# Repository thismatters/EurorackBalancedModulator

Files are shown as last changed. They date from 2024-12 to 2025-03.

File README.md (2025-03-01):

# Balanced Modulator

The Balanced Modulator combines to audio signals to create interesting overtones, not unlike a ring modulator but lacking many sidebands.

The circuit here is based on the [Yusynth Double Balanced Modulator](https://yusynth.net/Modular/EN/RINGMOD/index.html) with minor tweaks to make it more Eurorack friendly. The changes I've made are thus:
* Selected resistors appropriate for +/-12V rails,
* Added polarity protection so that a backward power header doesn't fry anything (twin series schotty diodes: BAT54SL),
* Full surface mount design,
* Reduced module to a single balanced modulator.

The Yusynth page is a treasure trove of information about this circuit that I am too amateur to claim as my own; please read that outstanding page before using this circuit. The page provides many details and other implementations of this circuit that you may find suitable.

The KiCAD project here uses the library/footprints [found in my companion repo](https://github.com/thismatters/EurorackKiCAD).

## Width

12hp on an Intellijel 1U rack.

## Inputs

Jacks:
- Carrier Signal: `A sin(f_1 t)`
- Modulating Signal: `B sin(f_2 t)`

## Outputs

Output jack for modulated signal: `A sin((f_1 + f_2) t) + A sin((f_1 - f_2) t)`

## Adjustment

* Set up the module to be in "AC" mode (see below).
* Set a VCO to output 1000Hz sine wave and connect it to the "carrier" input.
* Connect an oscilloscope to the output of the module.
* Adjust RV2 until the module output is flat.
* Move the VCO output to the "modulating" input.
* Adjust RV1 until the module output is flat.

### Choose Operating Mode

There are three sets of jumpers for setting whether the inputs and outputs will be AC or DC coupled.
Use three jumpers to choose how the signals will be coupled.

## Vendors

There are part numbers in the [BOM](balanced-modulator.csv) for many of the parts (not for basic passives though) at the following vendors:

* [Mouser](https://www.mouser.com): Needs no introduction. Get your ICs from here (or [digikey](https://www.digikey.com)).
* [Tayda Electronics](https://www.taydaelectronics.com/): Good supplier for passive components; audio jacks, and potentiometers. Their audio jacks are slightly smaller than the thonkiconn from thonk.
* [Love My Switches](https://lovemyswitches.com/): Has [really good knobs](https://lovemyswitches.com/anodized-aluminum-knob-the-lo-fi-1-4-smooth-shaft-12-5mm-od/) to go on those potentiometers!
* [OSHPark](https://oshpark.com/): Fast and (relatively) cheap PCB manufacturer. [V0 PCB works great!](https://oshpark.com/shared_projects/MmM817Fr)

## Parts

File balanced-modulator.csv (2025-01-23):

# | Reference | Qty | Value | Footprint | DNP | Vendor | PartNum
1 | C1, C2 | 2 | 22u 50V | Capacitor_THT:CP_Radial_D5.0mm_P2.50mm
2 | C3 | 1 | 100n | Capacitor_SMD:C_0805_2012Metric
3 | C4 | 1 | 100u 16V | Capacitor_THT:CP_Radial_D5.0mm_P2.50mm
4 | C5, C6, C7 | 3 | 1u box | Eurorack:C_Rect_Horizontal_L7.2mm_W11
5 | D1, D2 | 2 | BAT54S | Package_TO_SOT_SMD:SOT-23 |  | Mouser | 863-BAT54SLT1G
6 | J1 | 1 | Conn_02x05_Odd_Even | Eurorack:PinHeader_2x05_P2.54mm_Vertical |  | Tayda | A-2939
7 | J2, J5 | 2 | Conn_01x03_Socket | Connector_PinSocket_2.54mm:PinSocket_1x03_P2.54mm_Vertical
8 | J3, J4 | 2 | Conn_01x03_Pin | Connector_PinHeader_2.54mm:PinHeader_1x03_P2.54mm_Vertical
9 | J8 | 1 | carrier | Eurorack:AudioJack2_Tayda_A-2566 |  | Tayda | A-2566
10 | J9 | 1 | modulating | Eurorack:AudioJack2_Tayda_A-2566 |  | Tayda | A-2566
11 | J10 | 1 | out | Eurorack:AudioJack2_Tayda_A-2566 |  | Tayda | A-2566
12 | JP1, JP2, JP3 | 3 | Jumper_3_Bridged12 | Connector_PinHeader_2.54mm:PinHeader_1x03_P2.54mm_Horizontal
13 | M1, M3, M4, M6 | 4 | Screw | Eurorack:Screw_M2.5x0.45-6mm |  | Digikey | 36-29301-ND
14 | M2, M5 | 2 | Standoff | Eurorack:Standoff_M2.5x0.45-11mm |  | Digikey | 732-10549-ND
15 | R1, R2 | 2 | 10 | Resistor_SMD:R_0805_2012Metric
16 | R3, R10 | 2 | 180K | Resistor_SMD:R_0805_2012Metric
17 | R4, R7 | 2 | 12K | Resistor_SMD:R_0805_2012Metric
18 | R5, R6, R11, R14 | 4 | 2.7K | Resistor_SMD:R_0805_2012Metric
19 | R8, R9 | 2 | 1.5K | Resistor_SMD:R_0805_2012Metric
20 | R12, R13, R15 | 3 | 6.8K | Resistor_SMD:R_0805_2012Metric
21 | R16, R17, R20, R21 | 4 | 15K | Resistor_SMD:R_0805_2012Metric
22 | R18, R19 | 2 | 1.2K | Resistor_SMD:R_0805_2012Metric
23 | R22 | 1 | 10K | Resistor_SMD:R_0805_2012Metric
24 | R23 | 1 | 68K | Resistor_SMD:R_0805_2012Metric
25 | R24 | 1 | 1K | Resistor_SMD:R_0805_2012Metric
26 | RV1 | 1 | 500 | Potentiometer_THT:Potentiometer_Bourns_3296W_Vertical
27 | RV2 | 1 | 200 | Potentiometer_THT:Potentiometer_Bourns_3296W_Vertical
28 | U1 | 1 | MC1496 | Package_SO:SOIC-14_3.9x8.7mm_P1.27mm |  | Mouser | 863-MC1496BDR2G
29 | U2 | 1 | TL072 | Package_SO:SOIC-8_3.9x4.9mm_P1.27mm |  | Mouser | 595-TL072CDR

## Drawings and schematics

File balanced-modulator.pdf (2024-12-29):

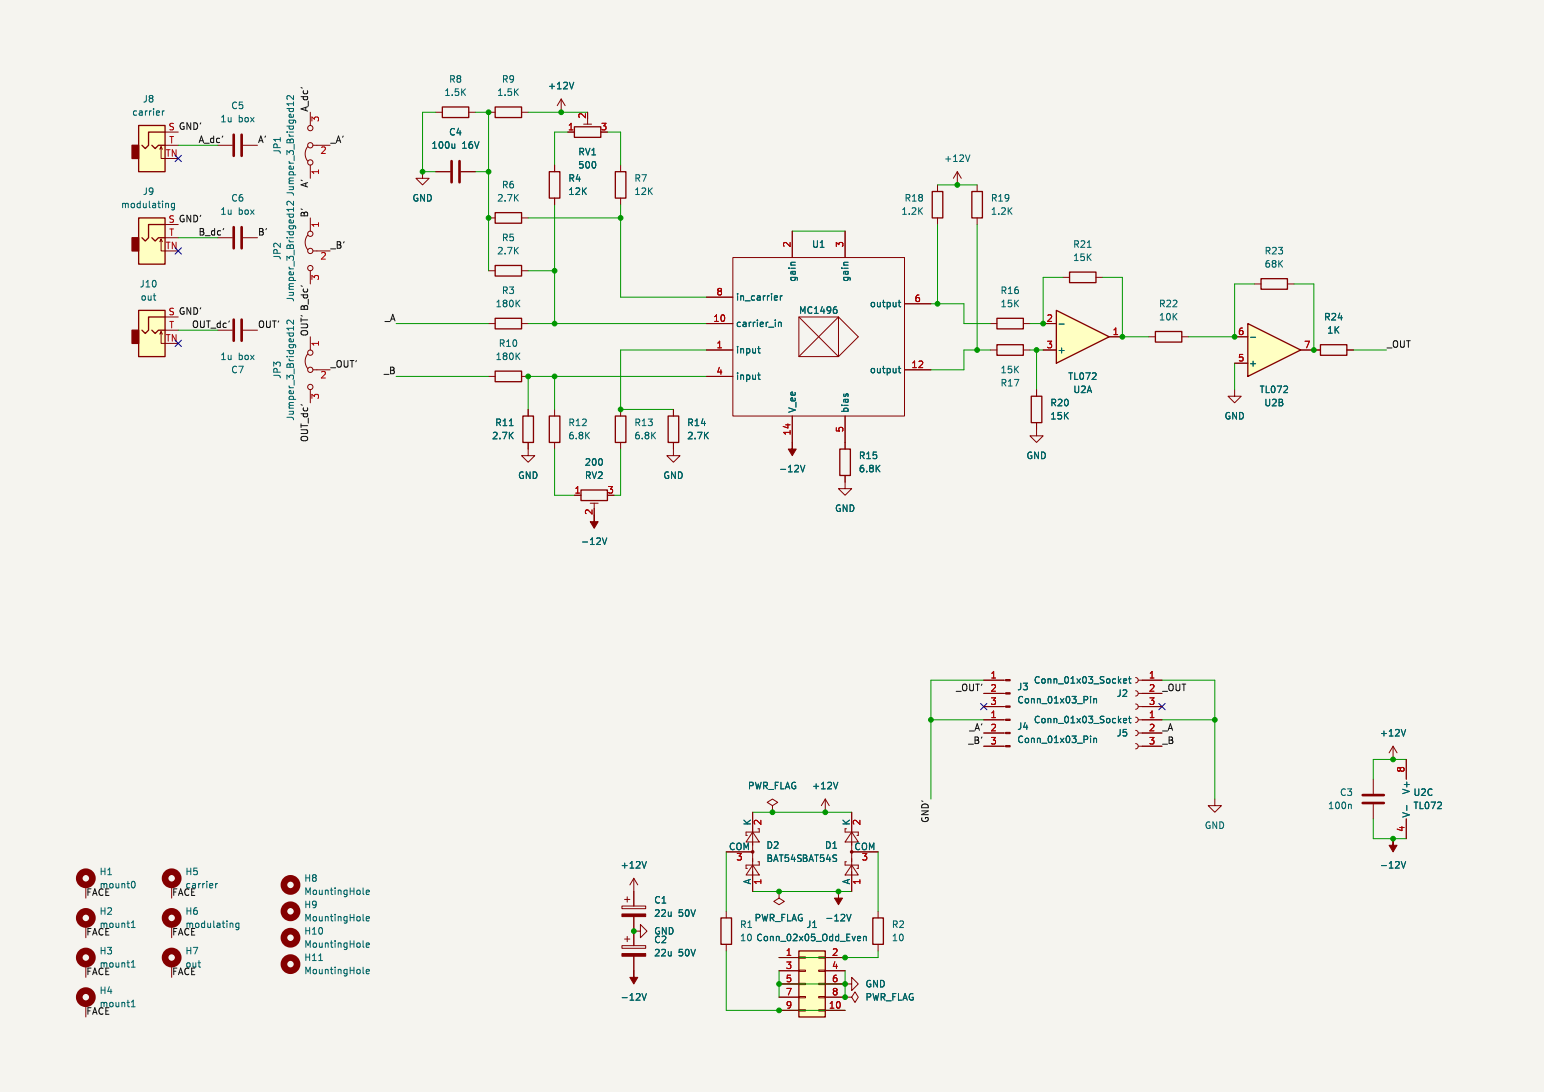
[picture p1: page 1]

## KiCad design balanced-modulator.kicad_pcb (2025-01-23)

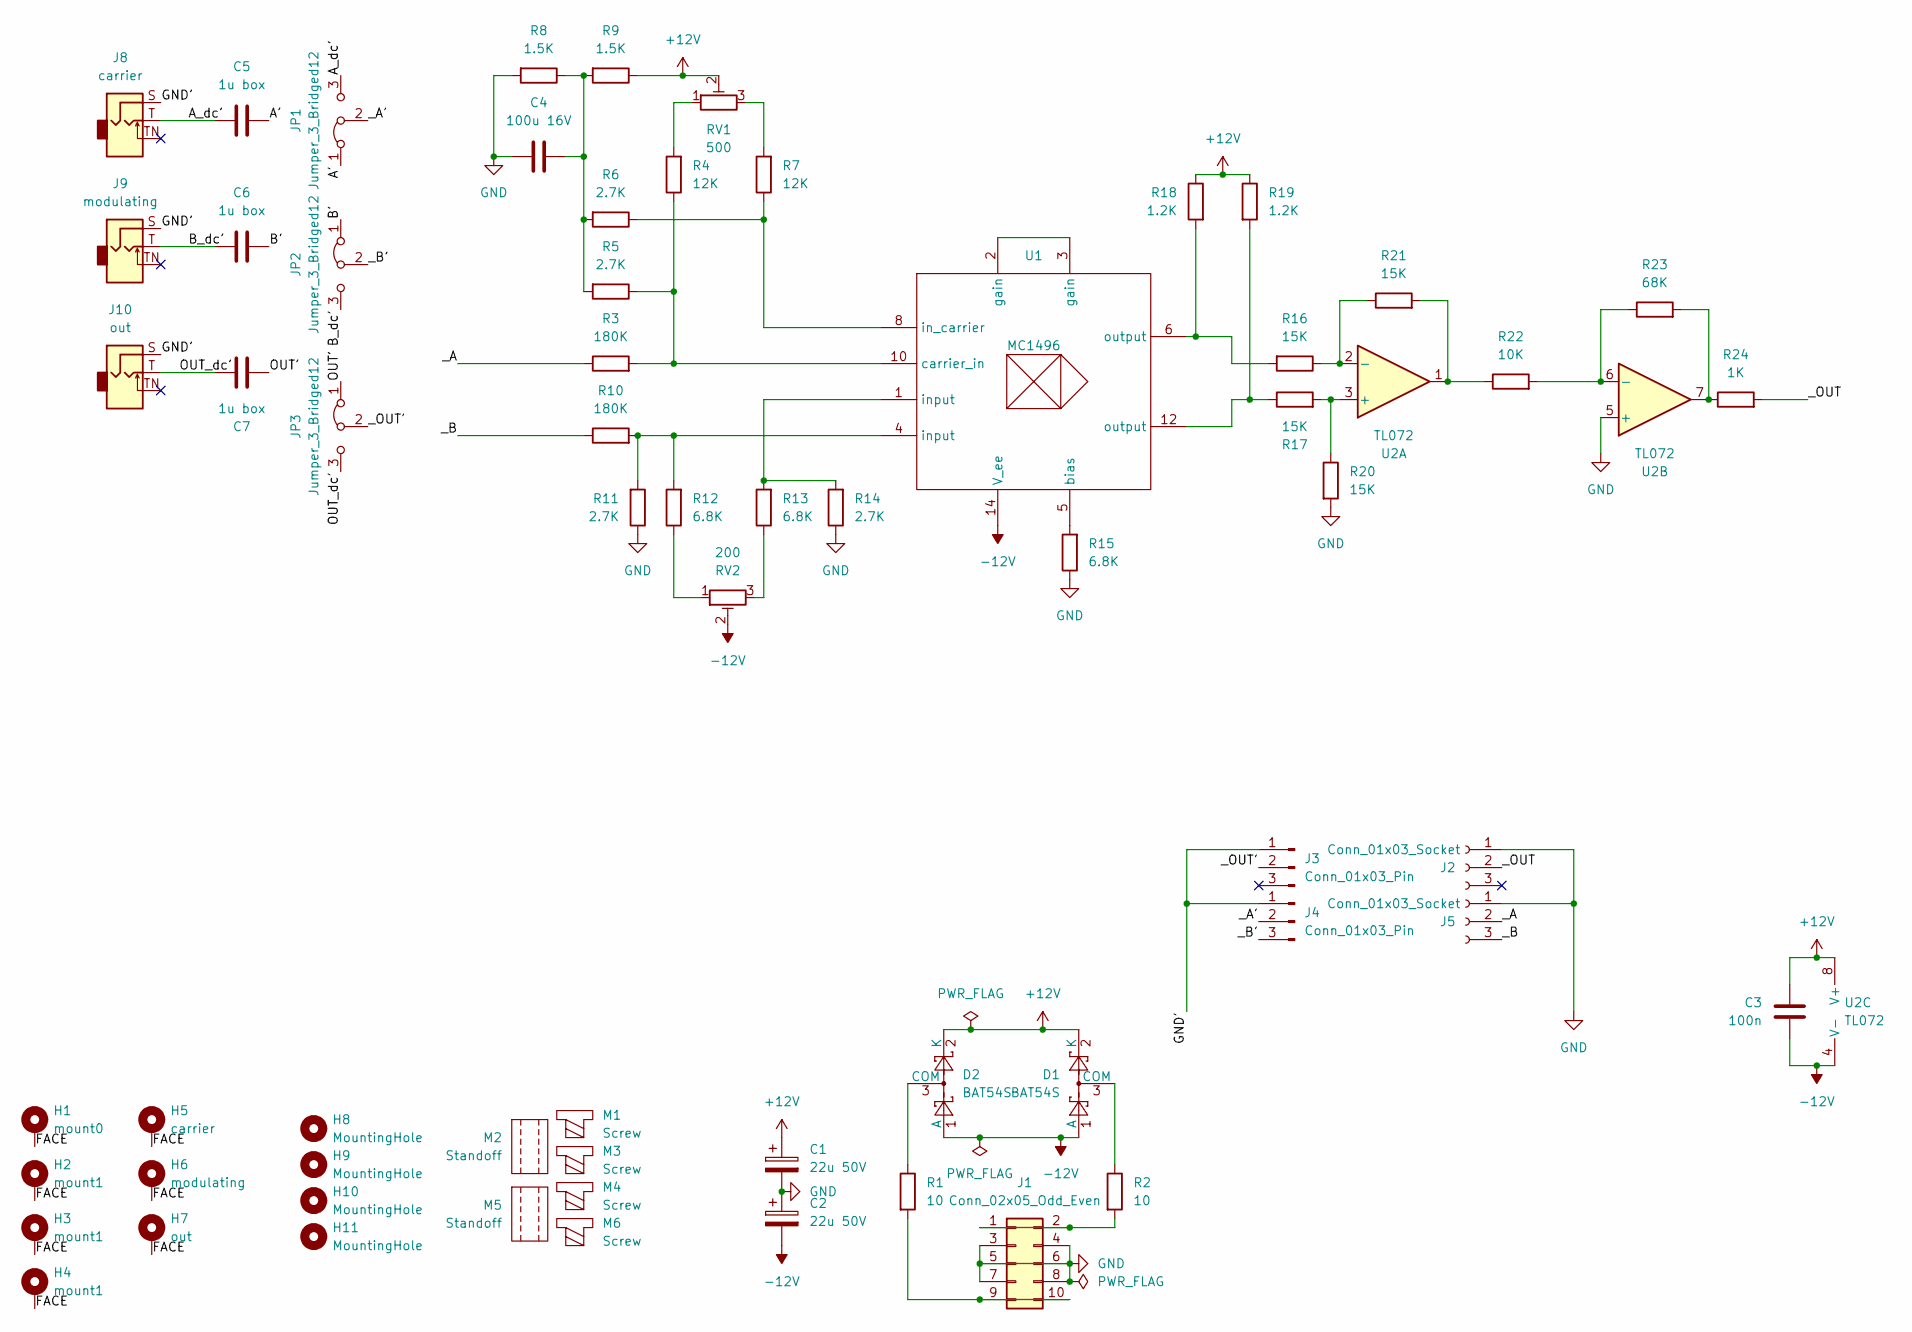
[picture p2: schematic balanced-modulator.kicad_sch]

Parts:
C1, C2: 22u 50V; CP_Radial_D5.0mm_P2.50mm
C3: 100n; C_0805_2012Metric
C4: 100u 16V; CP_Radial_D5.0mm_P2.50mm
C5, C6, C7: 1u box; C_Rect_Horizontal_L7.2mm_W11
D1, D2: BAT54S; SOT-23; PartNum 863-BAT54SLT1G
H1: mount0; Mech-MountingHole
H2, H3, H4: mount1; Mech-MountingHole
H5: carrier; Mech-AudioJack-Hole-Input
H6: modulating; Mech-AudioJack-Hole-Input
H7: out; Mech-AudioJack-Hole-Output
H8, H9, H10, H11: MountingHole; MountingHole_2.7mm_M2.5
J1: Conn_02x05_Odd_Even; PinHeader_2x05_P2.54mm_Vertical; PartNum A-2939
J2, J5: Conn_01x03_Socket; PinSocket_1x03_P2.54mm_Vertical
J3, J4: Conn_01x03_Pin; PinHeader_1x03_P2.54mm_Vertical
J8: carrier; AudioJack2_Tayda_A-2566; PartNum A-2566
J9: modulating; AudioJack2_Tayda_A-2566; PartNum A-2566
J10: out; AudioJack2_Tayda_A-2566; PartNum A-2566
JP1, JP2, JP3: Jumper_3_Bridged12; PinHeader_1x03_P2.54mm_Horizontal
M1, M3, M4, M6: Screw; Screw_M2.5x0.45-6mm; PartNum 36-29301-ND
M2, M5: Standoff; Standoff_M2.5x0.45-11mm; PartNum 732-10549-ND
R1, R2: 10; R_0805_2012Metric
R3, R10: 180K; R_0805_2012Metric
R4, R7: 12K; R_0805_2012Metric
R5, R6, R11, R14: 2.7K; R_0805_2012Metric
R8, R9: 1.5K; R_0805_2012Metric
R12, R13, R15: 6.8K; R_0805_2012Metric
R16, R17, R20, R21: 15K; R_0805_2012Metric
R18, R19: 1.2K; R_0805_2012Metric
R22: 10K; R_0805_2012Metric
R23: 68K; R_0805_2012Metric
R24: 1K; R_0805_2012Metric
RV1: 500; Potentiometer_Bourns_3296W_Vertical
RV2: 200; Potentiometer_Bourns_3296W_Vertical
U1: MC1496; SOIC-14_3.9x8.7mm_P1.27mm; PartNum 863-MC1496BDR2G
U2: TL072; SOIC-8_3.9x4.9mm_P1.27mm; PartNum 595-TL072CDR

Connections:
+12V: C1.1, C3.1, D1.2 (K), D2.2 (K), R9.1, R18.1, R19.1, RV1.2, U2.8 (V+)
-12V: C2.2, C3.2, D1.1 (A), D2.1 (A), RV2.2, U1.14 (V_ee), U2.4 (V-)
/A': C5.1, JP1.1 (A)
/A_dc': C5.2, J8.T, JP1.3 (B)
/B': C6.1, JP2.1 (A)
/B_dc': C6.2, J9.T, JP2.3 (B)
/FACE: H1.1, H2.1, H3.1, H4.1, H5.1, H6.1, H7.1
/GND': J3.1, J4.1, J8.S, J9.S, J10.S
/OUT': C7.2, JP3.1 (A)
/OUT_dc': C7.1, J10.T, JP3.3 (B)
/_A: J5.2, R3.1
/_A': J4.2, JP1.2 (C)
/_B: J5.3, R10.1
/_B': J4.3, JP2.2 (C)
/_OUT: J2.2, R24.2
/_OUT': J3.2, JP3.2 (C)
GND: C1.2, C2.1, C4.1, J1.3, J1.4, J1.5, J1.6, J1.7, J1.8, J2.1, J5.1, R8.2, R11.1, R14.1, R15.1, R20.2, U2.5 (+)
unnamed: C4.2, R5.2, R6.2, R8.1, R9.2
unnamed: D1.3 (COM), R2.1
unnamed: D2.3 (COM), R1.1
unnamed: J1.1, J1.2, R2.2
unnamed: J1.9, J1.10, R1.2
unnamed: R4.2, RV1.1
unnamed: R7.2, RV1.3
unnamed: R10.2, R11.2, R12.2, U1.4 (input)
unnamed: R12.1, RV2.1
unnamed: R13.1, RV2.3
unnamed: R13.2, R14.2, U1.1 (input)
unnamed: R16.2, R18.2, U1.6 (output)
unnamed: R17.1, R19.2, U1.12 (output)
unnamed: R21.2, R22.1, U2.1
unnamed: R23.2, R24.1, U2.7
unnamed: R15.2, U1.5 (bias)
unnamed: R3.2, R4.1, R5.1, U1.10 (carrier_in)
unnamed: U1.2 (gain), U1.3 (gain)
unnamed: R6.1, R7.1, U1.8 (in_carrier)
unnamed: R17.2, R20.1, U2.3 (+)
unnamed: R16.1, R21.1, U2.2 (-)
unnamed: R22.2, R23.1, U2.6 (-)

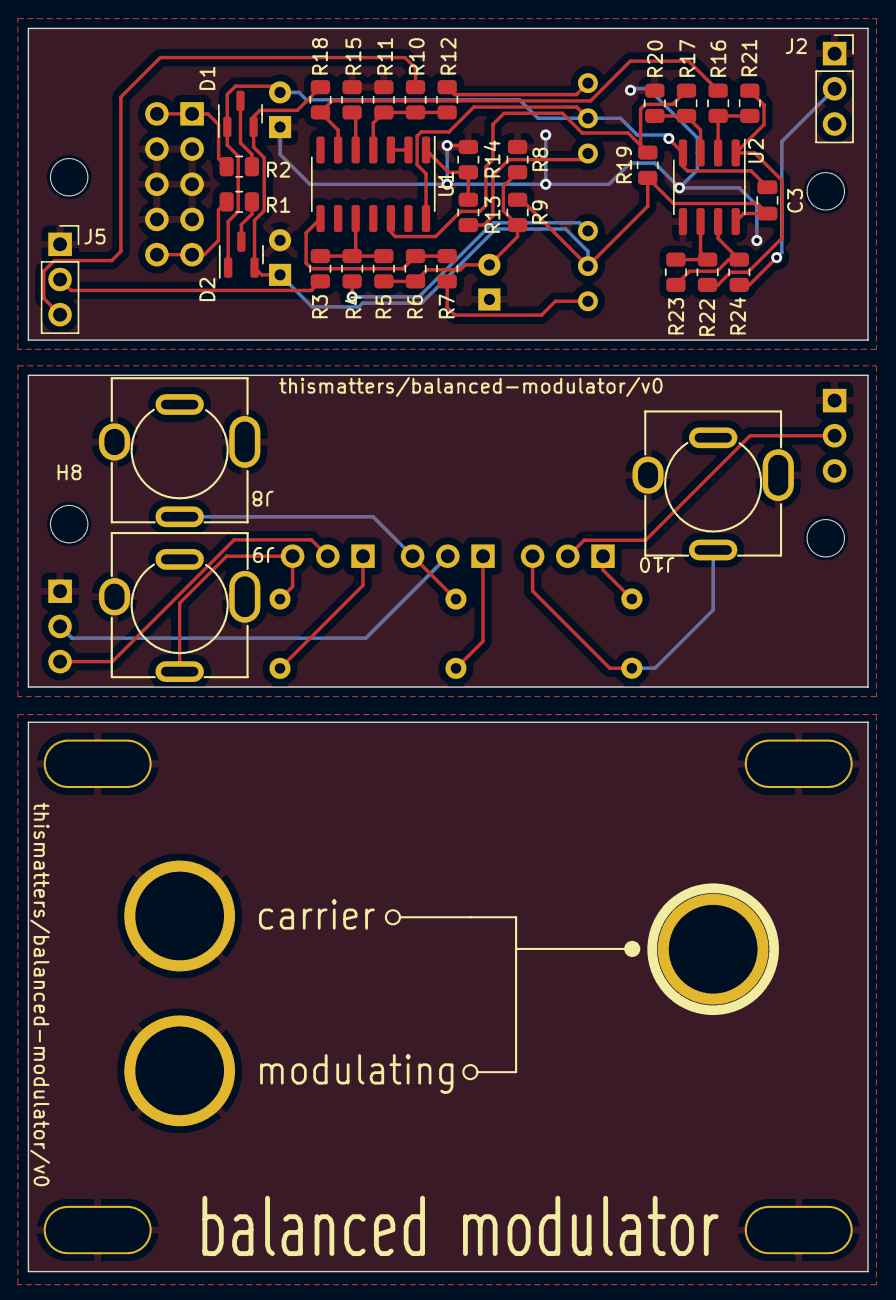
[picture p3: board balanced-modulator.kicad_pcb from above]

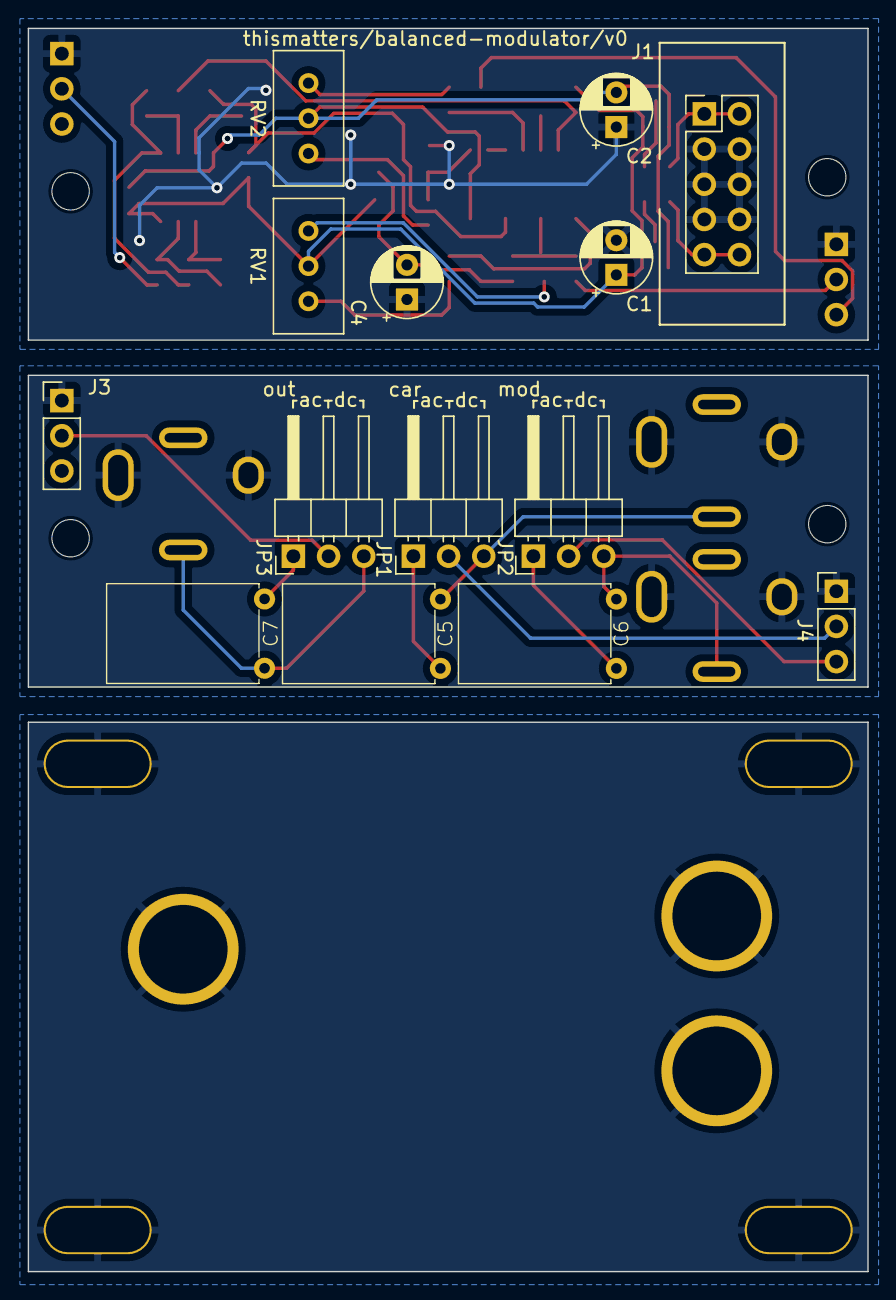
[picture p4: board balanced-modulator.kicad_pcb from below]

Board: 2 copper layers, 60.6 x 89.7 mm, 59 parts (14 on the bottom side), 39 nets.

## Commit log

2024-12-29 board + readme
    [balanced-modulator.csv, balanced-modulator.kicad_pcb, balanced-modulator.kicad_sch]
2025-01-01 adding part number
    [balanced-modulator.csv, balanced-modulator.kicad_pcb, balanced-modulator.kicad_sch]
2025-01-23 ready for v0 manu
    [balanced-modulator.csv, balanced-modulator.kicad_pcb, balanced-modulator.kicad_sch]
2025-03-01 prototype built
